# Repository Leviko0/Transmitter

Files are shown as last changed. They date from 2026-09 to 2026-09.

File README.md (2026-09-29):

# Transmitter

Transmitter based on ESP32 and ESPNOW for a RC tracked vehicle. It utilizes the TI BQ24075 IC for power management, so the transmitter can switch between the battery as a power supply and the usb-c connector. It used the NCV68261 for reverse current and reverse polarity protection.

## Hardware overview

- **MCU:** ESP32-S3-WROOM-1
- **Power management:** TI BQ24075 for switching between battery and USB-C power.
- **Protection:** NCV68261 for reverse current/polarity protection
- **Regulator:** TPS63021 Buck-Boost, 3.3V rail
- **Input:** push buttons for vehicle control
- **Connectivity:** USB-C (USB 2.0) for charging/data, plus a header reserved for a display

Schematic:


PCB:
PCB is still a work in progress

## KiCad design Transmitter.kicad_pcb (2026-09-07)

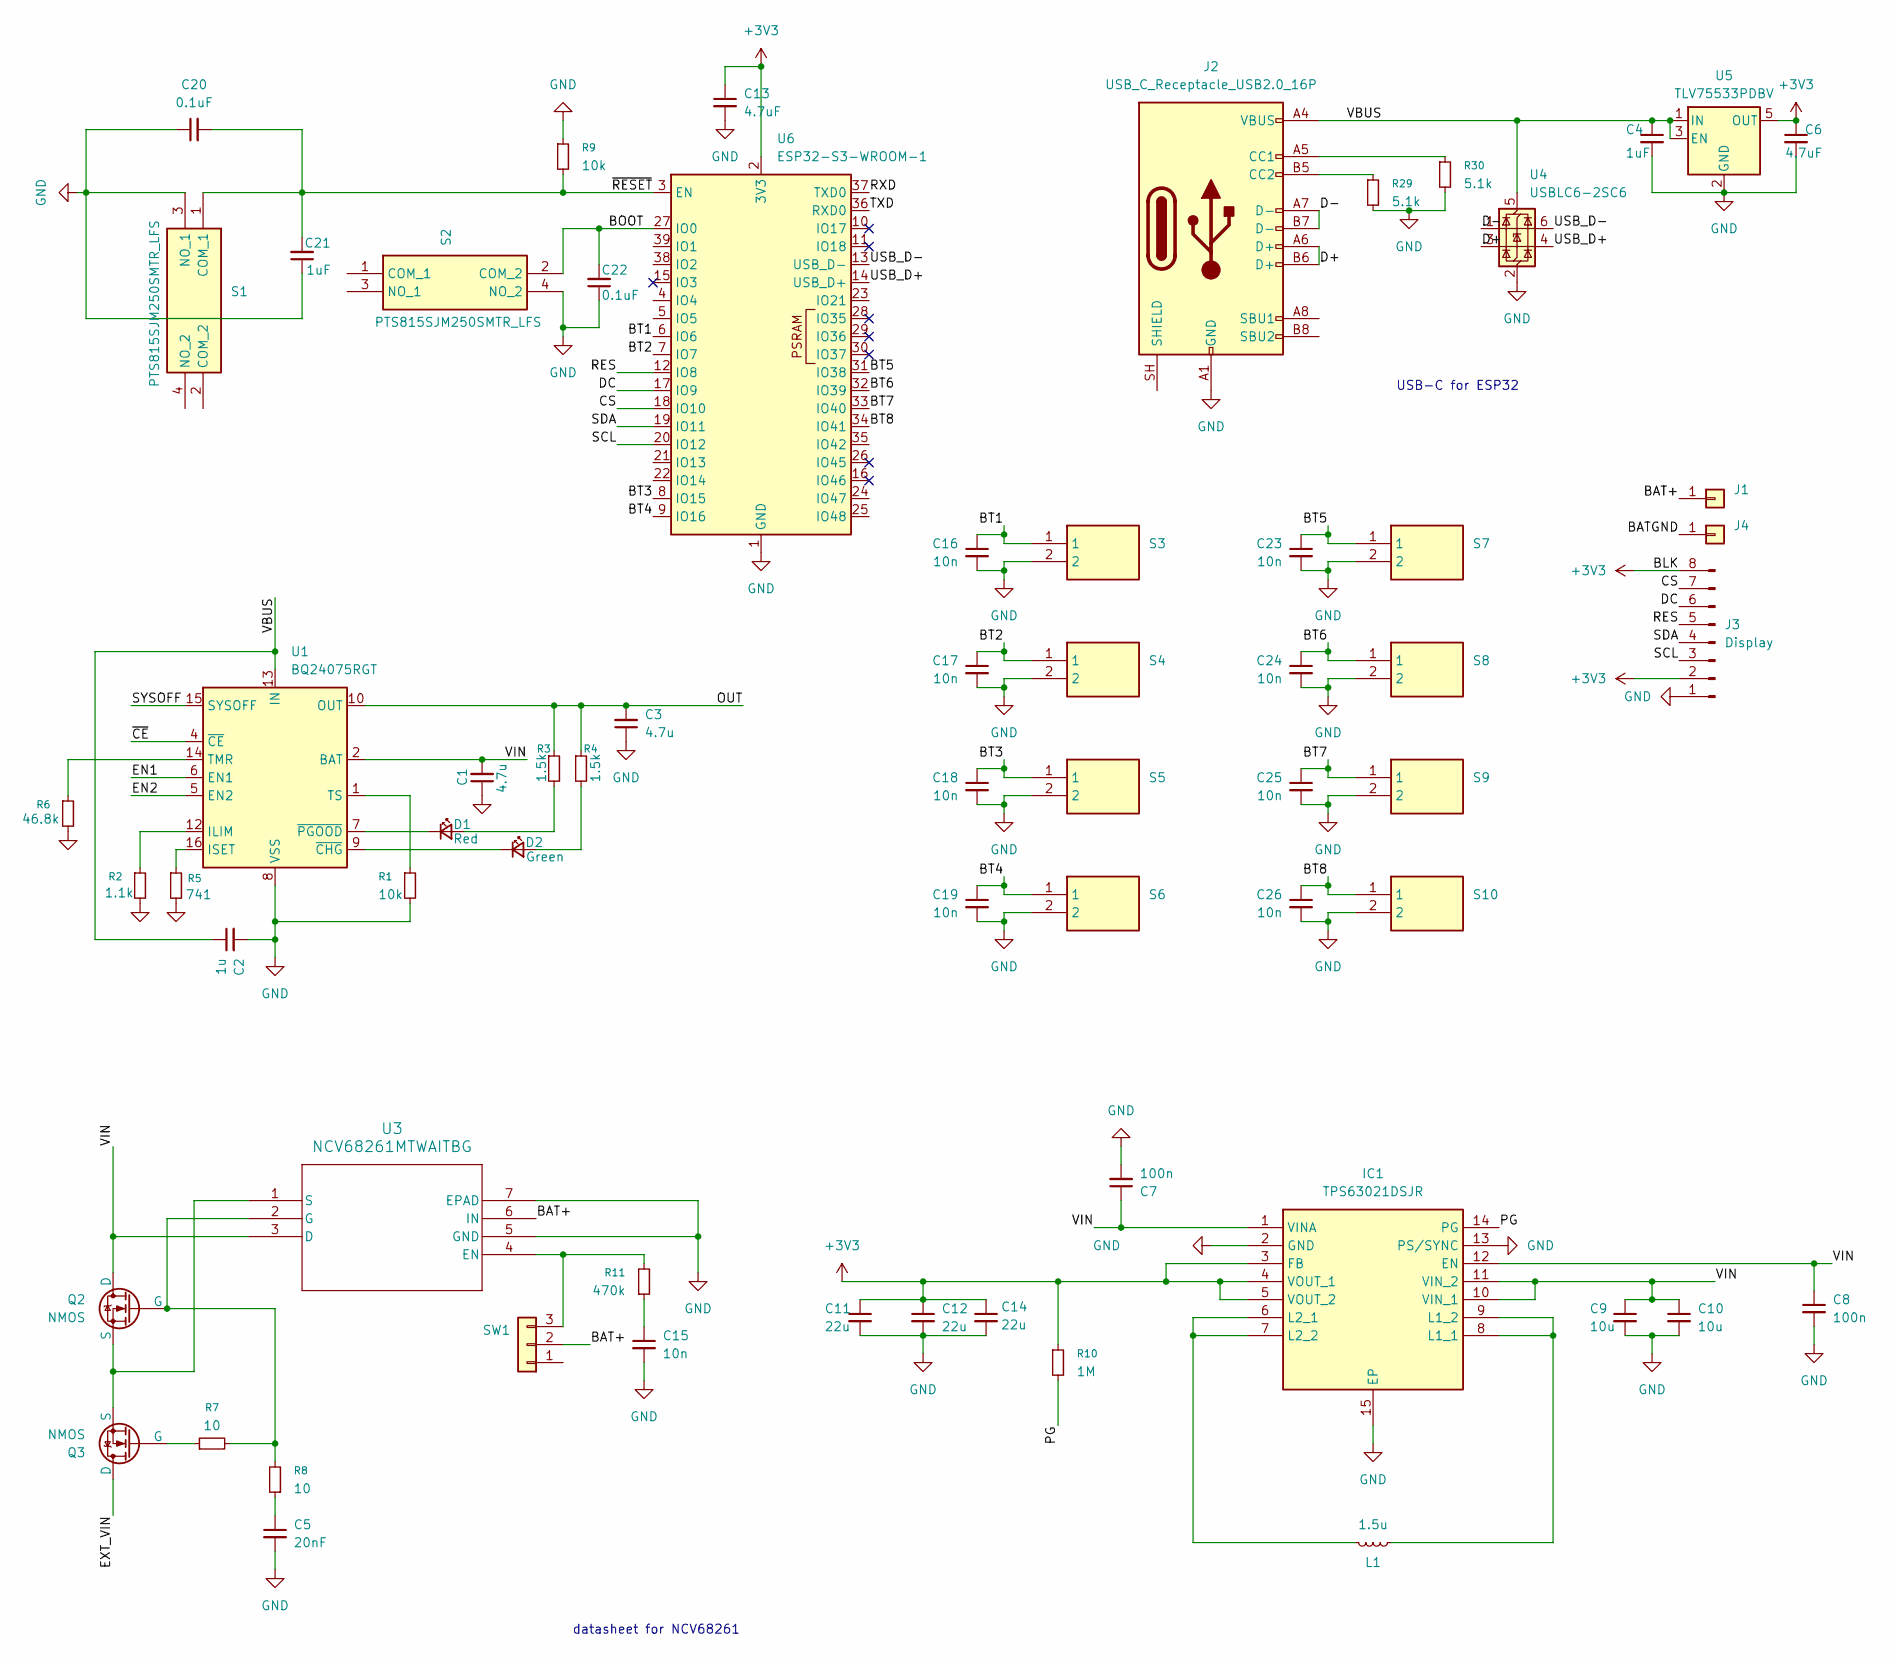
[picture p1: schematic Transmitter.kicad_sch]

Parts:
C1, C3: 4.7u; C_0603_1608Metric
C2: 1u; C_0603_1608Metric
C4, C21: 1uF; C_0603_1608Metric
C5: 20nF; C_0603_1608Metric
C6, C13: 4.7uF; C_0603_1608Metric
C7, C8: 100n; C_0603_1608Metric
C9, C10: 10u; C_0805_2012Metric
C11, C12, C14: 22u; C_0805_2012Metric
C15, C16, C17, C18, C19, C23, C24, C25, C26: 10n; C_0603_1608Metric
C20, C22: 0.1uF; C_0603_1608Metric
D1: Red; LED_0603_1608Metric
D2: Green; LED_0603_1608Metric
IC1: TPS63021DSJR; SON50P300X400X100-15N-D; Mouser Part Number 595-TPS63021DSJR
J1, J4: Conn_01x01; SolderWirePad_1x01_SMD_3x6mm
J2: USB_C_Receptacle_USB2.0_16P; USB494000A
J3: Display; PinHeader_1x08_P2.54mm_Vertical
L1: 1.5u; INDPM4441X120N
Q2, Q3: NMOS; TO-263-3_TabPin2
R1, R9: 10k; R_0603_1608Metric
R2: 1.1k; R_0603_1608Metric
R3, R4: 1.5k; R_0603_1608Metric
R5: 741; R_0603_1608Metric
R6: 46.8k; R_0603_1608Metric
R7, R8: 10; R_0603_1608Metric
R10: 1M; R_0603_1608Metric
R11: 470k; R_0603_1608Metric
R29, R30: 5.1k; R_0603_1608Metric
S1, S2: PTS815SJM250SMTR_LFS; PTS815SJM250SMTRLFS; Manufacturer_Part_Number PTS815SJM250SMTR LFS; Mouser Part Number 611-PTS815SJM250SMTR
S3, S4, S5, S6, S7, S8, S9, S10: TLSA040T3JLFS; Manufacturer_Part_Number TLSA040T3JLFS
SW1: Conn_01x03; PinHeader_1x03_P2.54mm_Vertical
U1: BQ24075RGT; VQFN-16-1EP_3x3mm_P0.5mm_EP1.6x1.6mm
U3: NCV68261MTWAITBG; WDFNW6_511DW_ONS_OSI
U4: USBLC6-2SC6; SOT-23-6
U5: TLV75533PDBV; SOT-23-5
U6: ESP32-S3-WROOM-1

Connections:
+3V3: C6.1, C11.1, C12.1, C13.1, C14.1, IC1.3 (FB), IC1.4 (VOUT_1), IC1.5 (VOUT_2), J3.2, J3.8, R10.1, U5.5 (OUT), U6.2 (3V3)
/BAT+: J1.1 (Pin_1_1), SW1.2, U3.6 (IN)
/BATGND: J4.1 (Pin_1_1)
/BOOT: C22.2, S2.2 (COM_2), U6.27 (IO0)
/BT1: C16.1, S3.1, U6.6 (IO6)
/BT2: C17.1, S4.1, U6.7 (IO7)
/BT3: C18.1, S5.1, U6.8 (IO15)
/BT4: C19.1, S6.1, U6.9 (IO16)
/BT5: C23.1, S7.1, U6.31 (IO38)
/BT6: C24.1, S8.1, U6.32 (IO39)
/BT7: C25.1, S9.1, U6.33 (IO40)
/BT8: C26.1, S10.1, U6.34 (IO41)
/CS: J3.7, U6.18 (IO10)
/D+: J2.A6 (D+), J2.B6 (D+), U4.3 (I/O2)
/D-: J2.A7 (D-), J2.B7 (D-), U4.1 (I/O1)
/DC: J3.6, U6.17 (IO9)
/EN1: U1.6 (EN1)
/EN2: U1.5 (EN2)
/EXT_VIN: Q3.2 (D)
/OUT: C3.2, R3.1, R4.1, U1.10 (OUT), U1.11 (OUT)
/PG: IC1.14 (PG), R10.2
/RES: J3.5, U6.12 (IO8)
/RXD: U6.37 (TXD0)
/SCL: J3.3, U6.20 (IO12)
/SDA: J3.4, U6.19 (IO11)
/SYSOFF: U1.15 (SYSOFF)
/TXD: U6.36 (RXD0)
/USB_D+: U4.4 (I/O2), U6.14 (USB_D+)
/USB_D-: U4.6 (I/O1), U6.13 (USB_D-)
/VBUS: C2.1, C4.1, J2.A4 (VBUS), J2.A9 (VBUS), J2.B4 (VBUS), J2.B9 (VBUS), U1.13 (IN), U4.5 (VBUS), U5.1 (IN), U5.3 (EN)
/VIN: C1.2, C7.1, C8.1, C9.1, C10.1, IC1.1 (VINA), IC1.10 (VIN_1), IC1.11 (VIN_2), IC1.12 (EN), Q2.2 (D), U1.2 (BAT), U1.3 (BAT), U3.3 (D)
/~CE: U1.4 (~CE)
/~RESET: C20.2, C21.2, R9.2, S1.1 (COM_1), U6.3 (EN)
GND: C1.1, C2.2, C3.1, C4.2, C5.2, C6.2, C7.2, C8.2, C9.2, C10.2, C11.2, C12.2, C13.2, C14.2, C15.2, C16.2, C17.2, C18.2, C19.2, C20.1, C21.1, C22.1, C23.2, C24.2, C25.2, C26.2, IC1.2 (GND), IC1.13 (PS/SYNC), IC1.15 (EP), J2.A1 (GND), J2.A12 (GND), J2.B1 (GND), J2.B12 (GND), J3.1, R1.2, R2.2, R5.2, R6.2, R9.1, R29.2, R30.2, S1.3 (NO_1), S2.4 (NO_2), S3.2, S4.2, S5.2, S6.2, S7.2, S8.2, S9.2, S10.2, U1.8 (VSS), U1.17 (VSS), U3.5 (GND), U3.7 (EPAD), U4.2 (GND), U5.2 (GND), U6.1 (GND), U6.40 (GND), U6.41 (GND)
unnamed: C5.1, R8.1
unnamed: C15.1, R11.1
unnamed: D1.2 (A), R3.2
unnamed: D1.1 (K), U1.7 (~PGOOD)
unnamed: D2.2 (A), R4.2
unnamed: D2.1 (K), U1.9 (~CHG)
unnamed: IC1.8 (L1_1), IC1.9 (L1_2), L1.1
unnamed: IC1.6 (L2_1), IC1.7 (L2_2), L1.2
unnamed: J2.A5 (CC1), R30.1
unnamed: J2.B5 (CC2), R29.1
unnamed: Q2.1 (G), R7.2, R8.2, U3.2 (G)
unnamed: Q2.3 (S), Q3.3 (S), U3.1 (S)
unnamed: Q3.1 (G), R7.1
unnamed: R11.2, SW1.3, U3.4 (EN)
unnamed: R2.1, U1.12 (ILIM)
unnamed: R5.1, U1.16 (ISET)
unnamed: R6.1, U1.14 (TMR)
unnamed: R1.1, U1.1 (TS)

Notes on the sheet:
datasheet for NCV68261
USB-C for ESP32

Board: 2 copper layers, 65 parts (0 on the bottom side), 44 nets, no tracks yet.
